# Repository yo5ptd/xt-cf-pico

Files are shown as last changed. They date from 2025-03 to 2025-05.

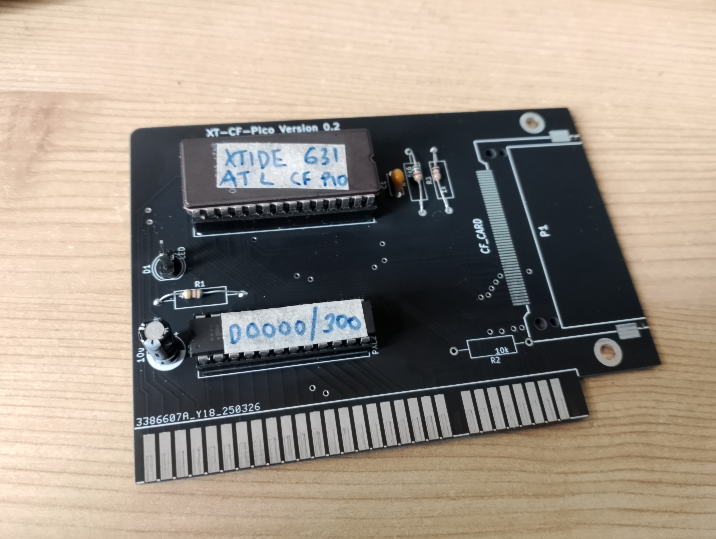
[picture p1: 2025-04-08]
images/during assembly.jpg

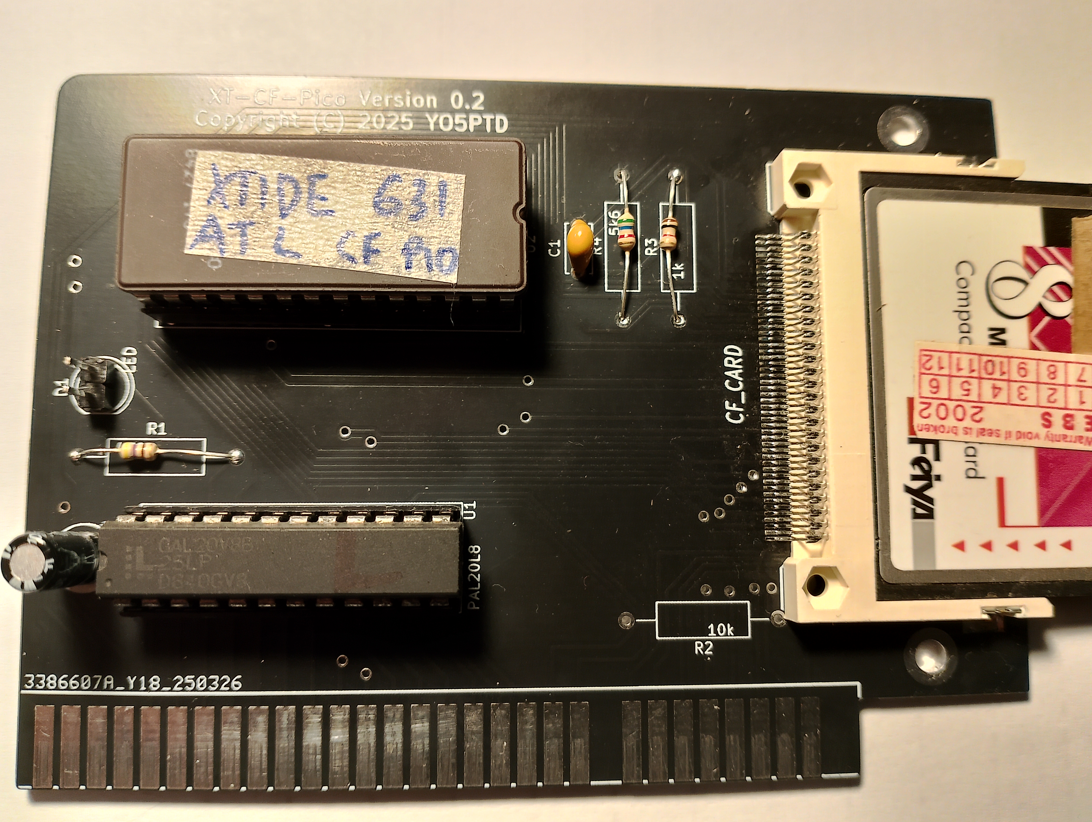
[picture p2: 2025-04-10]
images/assembled.jpg

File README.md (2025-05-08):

# xt-cf-pico   
8-bit ISA interface for Compact Flash cards with a single PLD  

## Introduction

XT-CF-Pico is a remake of Sergey Kiselev  [xt-cf-lite-v4]  efectively reverting glue logic IC back to PLD but still using through hole components. This card allows connecting a Compact Flash (CF) card to computers with ISA bus and using it as a mass storage device. The card also supports BIOS extension ROM, but if you have it e.g. in a network adapter already, it's safe to leave it out.

* 16 KiB EEPROM (28128) with either 8 or 16k images, no flash ROM.
* no jumpers, everything you configure in the PLD (GAL20V8, still available on Aliexpress, used in projects like C64 PLA20V8)

This is my first ISA board and first PLD design, it was easy to debug by just rewriting the GAL and EPROM! My motivation was that there were too many components and a lot of unused pins on Sergey's design.

## Hardware Documentation
The idea was to use a minimum amount of components that were available late '80s, keeping Sergey's concept of having them all through hole (except of course the CF adapter). Result was one GAL IC and one EPROM.

Download latest bios from https://www.xtideuniversalbios.org/binaries/ (I used IDE_ATL.BIN) and configure primary IDE (with xtidecfg.com) for XT CF BIU 8 (I used addr 0x300).
[XTCFG](images/biu.jpg) 

### Schematic and PCB Layout

[Schematic](KiCad/XT-CF-Pico-Schematic.pdf)

[PCB Layout](KiCad/XT-CF-Pico-Board.pdf)

[Assembled](images/assembled.jpg)

### Bill of Materials

Component Type | Reference | Description                             | Quantity | Possible Sources and Notes
-------------- | --------- | --------------------------------------- | -------- | --------------------------
PCB            |           | XT-CF-Pico 	                           | 1        | jlpcb
Capacitor      | C1        | 0.1 uF ceramic, 5.0 mm lead spacing     | 1        | 
Capacitor      | C2 	     | 10 uF electrolytic, 6.3 mm lead spacing | 1        | 
LED            | D1        | 5 m (T-1) LED indicator                 | 1        | You can use 2 pin jumper holder for external led
Connector      | P1        | Compact Flash Card connector            | 1        | 101D-TAAA-R01 from ATTEND  (this was the cheapest now, footprint was updated)
Resistor       | R1        | 470 Ohm, 1/4 W                          | 1        | Mouser 291-470-RC
Resistor       | R3        | 1 kOhm, 1/4 W                           | 1        | Mouser 291-1K-RC
Resistor       | R4        | 5.6 kOhm, 1/4 W                         | 1        | Mouser 291-5.6K-RC
Resistor       | R2        | 10 kOhm, 1/4 W                          | 0        | Note: Do not install, kept for historic reasons only (card present detection?)
IC             | U1        | 27128 EEPROM                            | 1        | mbm27128
IC Socket      | U1        | 28 pin 600 mil (wide) DIP socket        | 1        | optional
IC Socket      | U2        | 24 pin 300 mil (narrow) DIP socket      | 1        | optional

### Cost estimate for 5 boards

* PCB - 4.17 USD including shipping jlpcb
* GAL20V8 - 3.47 USD including shipping aliexpress
* 28C128 - 5.49 USD including shipping aliexpress
* 101D-TAAA-R01 attend - 10.4 including shipping from tme
* passives - 1USD or less (you can order them from tme to save on shipping)

Results a cost of around 5 USD per board (not including labor to assemble and program)

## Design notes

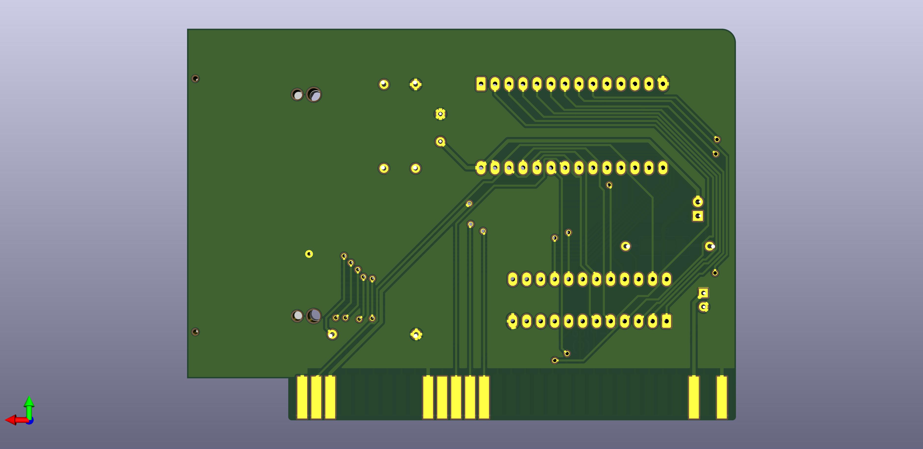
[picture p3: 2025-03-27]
images/xt-cf-back.jpg

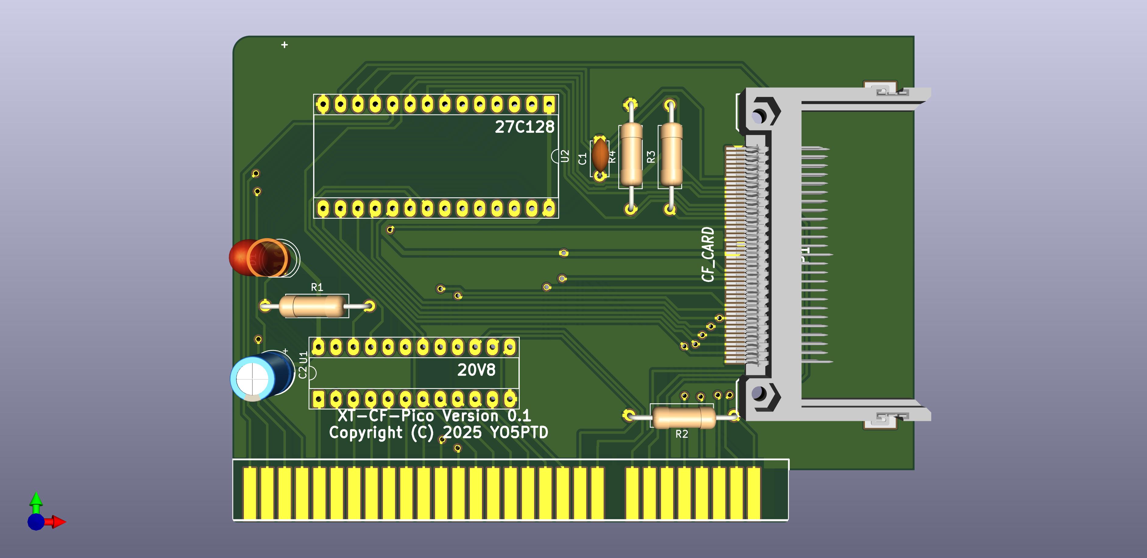
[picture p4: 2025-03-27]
images/xt-cf.jpg

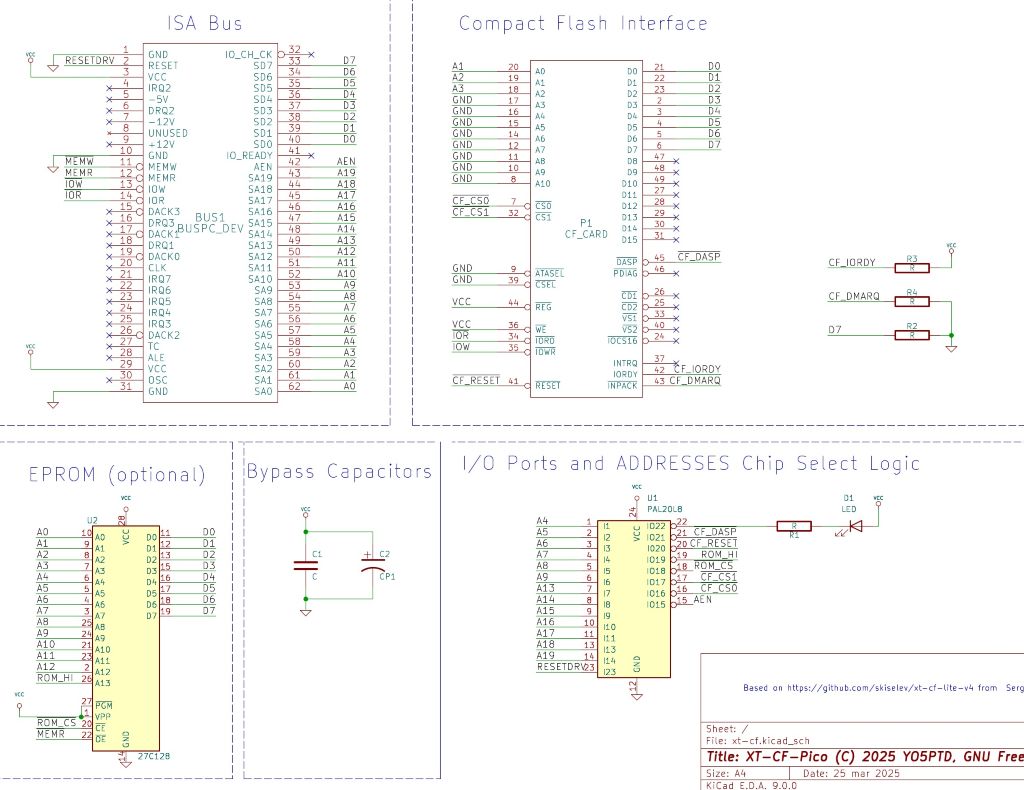
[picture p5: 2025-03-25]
images/sch.jpg

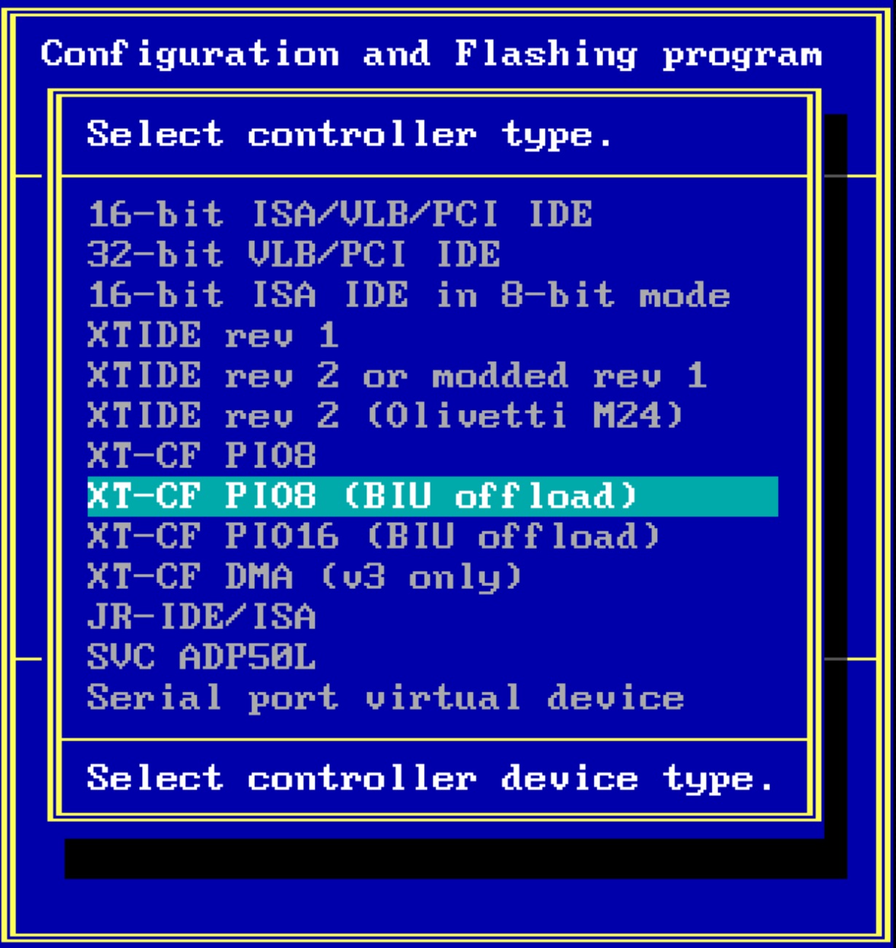
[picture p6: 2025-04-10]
images/biu.jpg

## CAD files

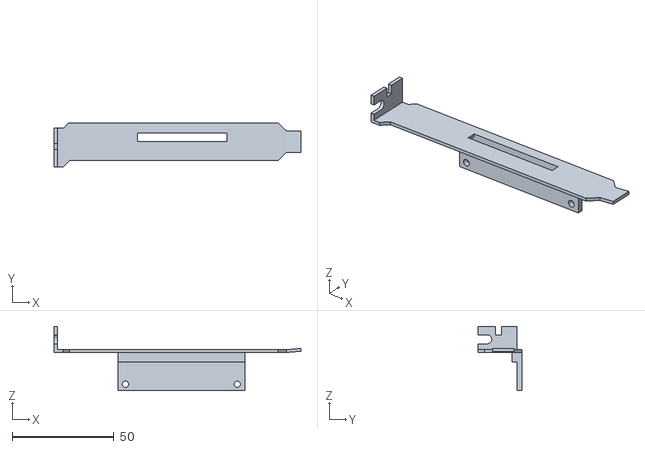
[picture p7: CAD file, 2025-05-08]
bracket/bracket.stl
121.4 x 21.6 x 31.5

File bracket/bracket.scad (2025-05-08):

resolution=32; // $fn
low_profile=0; // [0:false, 1:true]
bracket_thickness = 1.4; // base bracket depth

angled_bottom_tab = 1; // [0:false, 1:true]
decorative_hole=0; // [0:false, 1:true]
isa_slot=1; // [0:false, 1:true]
pcb_thickness=1.6;
top_tab_thickness = 1.6;
/* [Screw mount tabs] */

first_screw_tab_enabled = 1; // [0:false, 1:true]
second_screw_tab_enabled = 1; // [0:false, 1:true]
screw_mounts_on_bottom_of_pcb = 0; // [0:false, 1:true]
screw_mount_width = 7.5;
screw_mount_depth = 2.5;
screw_mount_hole_r = 1.55; // m3 bolt
screw_mount_thread_distance_base = 15.6;
screw_mount_inset_r = 2.9; // m3 bolt head
screw_mount_inset_depth = 0;
screw_mount_caulking = 0.5;

first_mount_x = 33.5;
mount_hole_distance = 55;
// If on top of the PCB, it is recommended to have this be at least the thickness of the PCB
screw_mount_y = 0;
second_mount_x = first_mount_x + mount_hole_distance;

/* [Round Holes] */
hole_1_enabled = 0; // [0:false, 1:true]
// X is offset from the first screw hole (i.e. the screw hole closest to the case mount cutout)
hole_1_x = 11.01;
// Y is offset from top of pcb
hole_1_y = 6.5;
hole_1_d = 9.5;

hole_2_enabled = 0; // [0:false, 1:true]
hole_2_x = 24.34;
hole_2_y = 6.5;
hole_2_d = 9.5;

hole_3_enabled = 0; // [0:false, 1:true]
hole_3_x = 63.41;
hole_3_y = 7;
hole_3_d = 6;

hole_4_enabled = 0; // [0:false, 1:true]
hole_4_x = 76.12;
hole_4_y = 7;
hole_4_d = 6;

hole_5_enabled = 0; // [0:false, 1:true]
hole_5_x = 37.69;
hole_5_y = 6.5;
hole_5_d = 9.5;

hole_6_enabled = 0; // [0:false, 1:true]
hole_6_x = 51.04;
hole_6_y = 6.5;
hole_6_d = 9.5;

/* [Rectangular Holes] */
// hole is at center of x,y positions
rectangular_hole_1_enabled = 1; // [0:false, 1:true]
// X is offset from the first screw hole (i.e. the screw hole closest to the case mount cutout)
rectangular_hole_1_x = 11.00;
// Y is offset from top of pcb
rectangular_hole_1_y = 6.5;
rectangular_hole_1_w = 5;
rectangular_hole_1_h = 10.5;

rectangular_hole_2_enabled = 1; // [0:false, 1:true]
rectangular_hole_2_x = 20;
rectangular_hole_2_y = 6.5;
rectangular_hole_2_w = 5;
rectangular_hole_2_h = 10.5;

rectangular_hole_3_enabled = 1; // [0:false, 1:true]
rectangular_hole_3_x = 29;
rectangular_hole_3_y = 6.5;
rectangular_hole_3_w = 5;
rectangular_hole_3_h = 10.5;

rectangular_hole_4_enabled = 1; // [0:false, 1:true]
rectangular_hole_4_x = 38;
rectangular_hole_4_y = 6.5;
rectangular_hole_4_w = 5;
rectangular_hole_4_h = 10.5;

rectangular_hole_5_enabled = 1; // [0:false, 1:true]
rectangular_hole_5_x = 45;
rectangular_hole_5_y = 6.5;
rectangular_hole_5_w = 5;
rectangular_hole_5_h = 10.5;

rectangular_hole_6_enabled = 0; // [0:false, 1:true]
rectangular_hole_6_x = 51.04;
rectangular_hole_6_y = 6.5;
rectangular_hole_6_w = 10.5;
rectangular_hole_6_h = 10.5;
// values taken from https://content.norcomp.net/rohspdfs/Connectors/PanelCutOuts/Panel_Cutout_D-Sub-Single.pdf

/* [D-Sub holes (Serial/VGA/Gameport)] */
// hole is at center of x,y positions
dsub_hole_1_type = 0; // [0:None, 15.46:DB-9(VGA/Serial), 23.79:DB-15(Gameport), 37.51:DB-25(Parallel)]
// X is offset from the first screw hole (i.e. the screw hole closest to the case mount cutout)
dsub_hole_1_x = 37.6;
// Y is offset from top of pcb
dsub_hole_1_y = 7.1;
dsub_hole_1_invert = 0; // [0:false, 1:true]

dsub_hole_2_type = 0; // [0:None, 15.46:DB-9(VGA/Serial), 23.79:DB-15(Gameport), 37.51:DB-25(Parallel)]
dsub_hole_2_x = 37.6;
dsub_hole_2_y = 7.1;
dsub_hole_2_invert = 0; // [0:false, 1:true]

dsub_hole_3_type = 0; // [0:None, 15.46:DB-9(VGA/Serial), 23.79:DB-15(Gameport), 37.51:DB-25(Parallel)]
dsub_hole_3_x = 37.6;
dsub_hole_3_y = 7.1;
dsub_hole_3_invert = 0; // [0:false, 1:true]

/* [DVI Hole]] */

dvi_hole_enabled = 0; // [0:false, 1:true]
dvi_hole_x = 37.6;
dvi_hole_y = 6;
dvi_hole_invert = 0; // [0:false, 1:true]


module __Customizer_Limit__ () {}  // This actually works
shown_by_customizer = 0; // [0:false, 1:true]

$fn = resolution;
bracket_width_length = low_profile? 71.46 : 112.78;
bracket_length = low_profile ? 79.20 : 120.02;
bracket_width = 18.42 + 0;
bottom_tab_width = 10.19 + 0;
bracket_bottom_tab_angle_length = (bracket_width - bottom_tab_width) / 2;

bracket_reinforce_width = bracket_width * .2;
bracket_reinforce_length = bracket_length * .78;

bracket_hole_dia = decorative_hole ? 4.75 : 0;
bracket_hole_distance = low_profile ? 66.19 : 107.01;

screw_mount_thread_distance = screw_mount_thread_distance_base + bracket_thickness;
screw_mount_length = screw_mount_thread_distance * 1.1 + bracket_thickness;

bracket_reinforce_depth = 0;
bracket_reinforce_offset_x = -6;
bracket_reinforce_offset_y = -5;


module prism(l, w, h){
     polyhedron(
         points=[[0,0,0], [l,0,0], [l,w,0], [0,w,0], [0,w,h], [l,w,h]],
         faces=[[0,1,2,3],[5,4,3,2],[0,4,5,1],[0,3,4],[5,2,1]]
         );
}

// top notch
notch_width = 2.54;
notch_length = 3.94-.86; // 3.94 - specified thickness of .86mm (vs actual thickness)

top_tab_width = 19.05; // had to fudge this
top_tab_length = 11.43;
top_tab_x = 0;
top_tab_y = 3.17; // 21.59 - 18.42
top_tab_screw_groove_dia = 4.42;
top_tab_screw_groove_fudge = -0.4; // kinda came out looking wrong so I'm faking it a bit here
top_tab_screw_groove_center = 3.18 + top_tab_screw_groove_fudge;
top_tab_screw_groove_distance = 6.35;
top_tab_screw_groove_translate_z = top_tab_length - top_tab_screw_groove_dia / 2 - top_tab_screw_groove_distance;

top_tab_useless_notch_length = 3.05;
top_tab_useless_notch_width = top_tab_screw_groove_distance - top_tab_screw_groove_dia / 2;
top_tab_useless_notch_z = top_tab_length - top_tab_useless_notch_width;
top_tab_useless_notch_y = top_tab_useless_notch_width / 2 + 8.05 - top_tab_useless_notch_length / 2;

translate([-top_tab_thickness + top_tab_x, -top_tab_y, 0]) difference() {
  cube([top_tab_thickness, top_tab_width, top_tab_length + bracket_thickness]);
  translate([-.5, -1, top_tab_screw_groove_translate_z + bracket_thickness]) {
    cube([top_tab_thickness + 1, top_tab_screw_groove_center * 2, top_tab_screw_groove_dia]);
    translate([1, top_tab_screw_groove_center * 2, top_tab_screw_groove_dia / 2])
      rotate([0, 90, 0])
      cylinder(r=top_tab_screw_groove_dia / 2, h=top_tab_thickness * 2, $fn=20, center=true);
  }
  translate([-.5, top_tab_useless_notch_y, top_tab_useless_notch_z + bracket_thickness]) {
    cube([top_tab_thickness + 1, top_tab_useless_notch_length, top_tab_useless_notch_width + 1]);
  }
}

// screw mounts
module screwmount(x) {
  
  translate([0, isa_slot? -screw_mount_y - screw_mount_depth : -bracket_width + screw_mount_y, 0]) // easier to be explicit here than factor it in the below statement
  translate([x - screw_mount_width / 2, bracket_width, -screw_mount_length + bracket_thickness])
    // cut out the threads
    difference() {
      union() {
        cube([screw_mount_width, screw_mount_depth, screw_mount_length]);
        //top caulking
        if ((isa_slot && bracket_width-screw_mount_y +screw_mount_caulking < bracket_width) || (!isa_slot &&  screw_mount_y + screw_mount_depth+ screw_mount_caulking < bracket_width)){
        difference(){
        translate([screw_mount_width, screw_mount_depth-.05, screw_mount_length-bracket_thickness-screw_mount_caulking +.05])
          rotate([90,0,180])
          prism(screw_mount_width,screw_mount_caulking+.05,screw_mount_caulking+.05);
        }
        }
        //bottom caulking
        if ((isa_slot && bracket_width-screw_mount_y -screw_mount_depth -screw_mount_caulking > 0) || (!isa_slot && screw_mount_y - screw_mount_caulking > 0)){
        translate([0, 0, screw_mount_length-bracket_thickness-screw_mount_caulking +.05])
          rotate([90,0,0])
          prism(screw_mount_width,screw_mount_caulking+.05,screw_mount_caulking+.05);
        }        
      }
       translate([screw_mount_width / 2, -2, screw_mount_length - screw_mount_thread_distance])
         rotate([0, 90, 90]) cylinder(r=screw_mount_hole_r, h=10, $fn=20);
      //inset
      translate([screw_mount_width / 2, ((isa_slot && screw_mounts_on_bottom_of_pcb) || (!isa_slot && !screw_mounts_on_bottom_of_pcb))?(screw_mount_depth - screw_mount_inset_depth + 0.01):(-0.01),
        screw_mount_length - screw_mount_thread_distance])
          rotate([0, 90, 90])
          cylinder(r=screw_mount_inset_r, h=screw_mount_inset_depth, $fn=20);
    }
    
///hack
translate([first_mount_x+ screw_mount_width / 2, bracket_width-screw_mount_depth, -screw_mount_length + bracket_thickness])
     cube([second_mount_x-first_mount_x-screw_mount_width , screw_mount_depth, screw_mount_length]);
    
translate([first_mount_x- screw_mount_width / 2, bracket_width-2*screw_mount_depth, -6 + bracket_thickness])
     cube([second_mount_x-first_mount_x+screw_mount_width , screw_mount_depth, 6]);
}

if (first_screw_tab_enabled){
  screwmount(first_mount_x);  
}
if (second_screw_tab_enabled) {
  screwmount(second_mount_x);
}

// bottom notch
shiftover_width = top_tab_y;
shiftover_length = 2.92;
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

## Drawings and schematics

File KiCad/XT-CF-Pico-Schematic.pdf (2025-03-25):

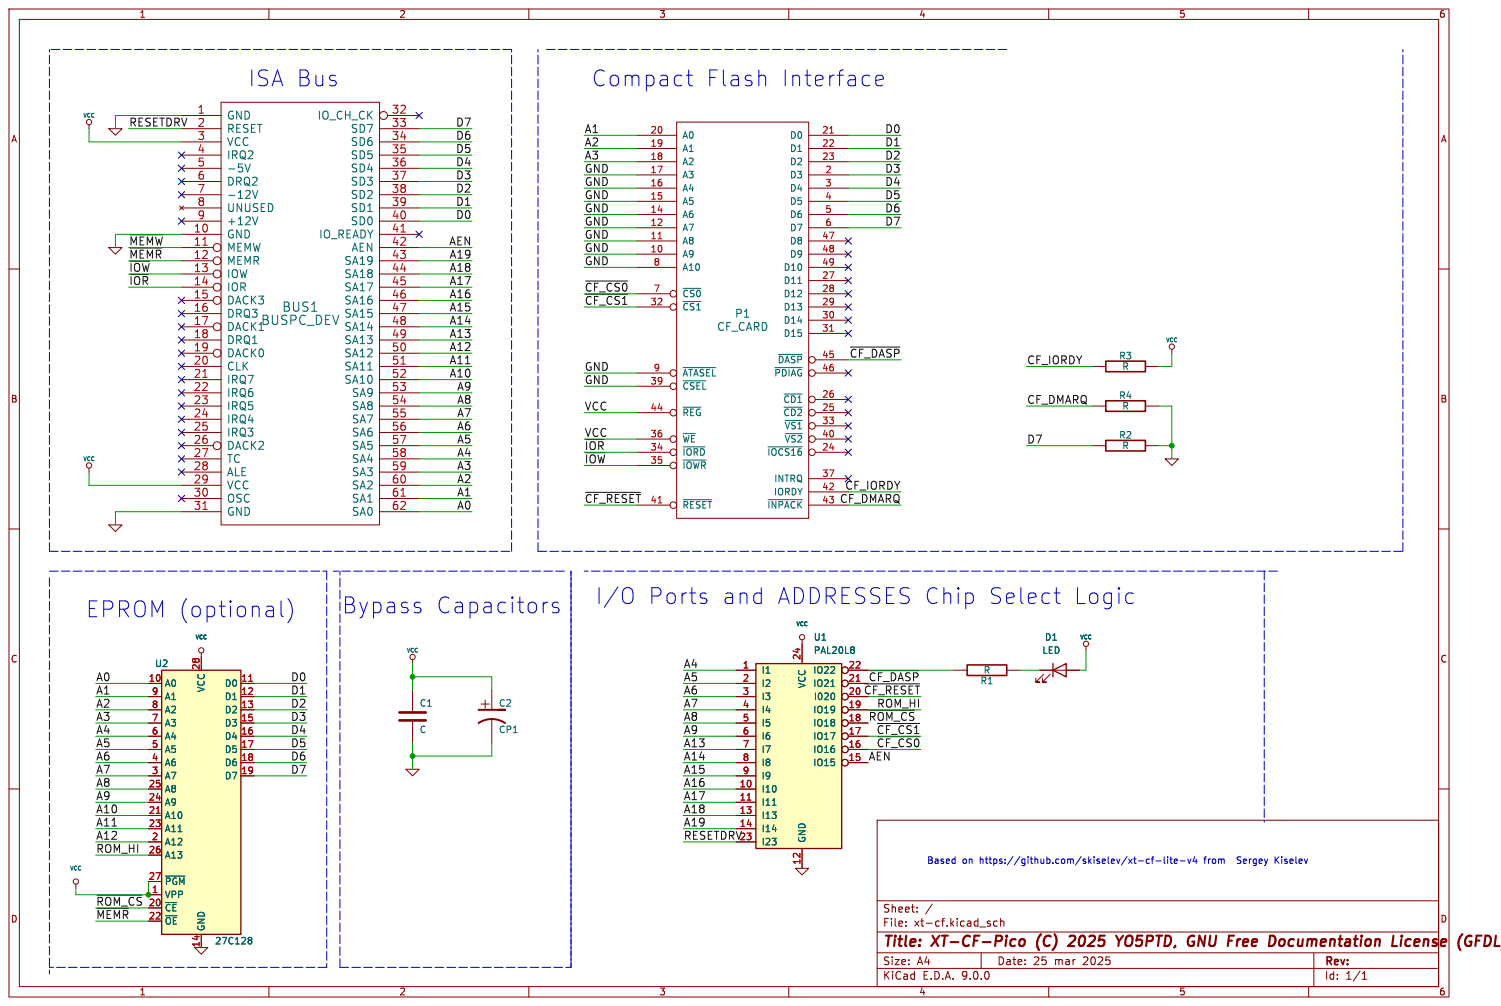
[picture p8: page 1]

I/O Ports and ADDRESSES Chip Select Logic

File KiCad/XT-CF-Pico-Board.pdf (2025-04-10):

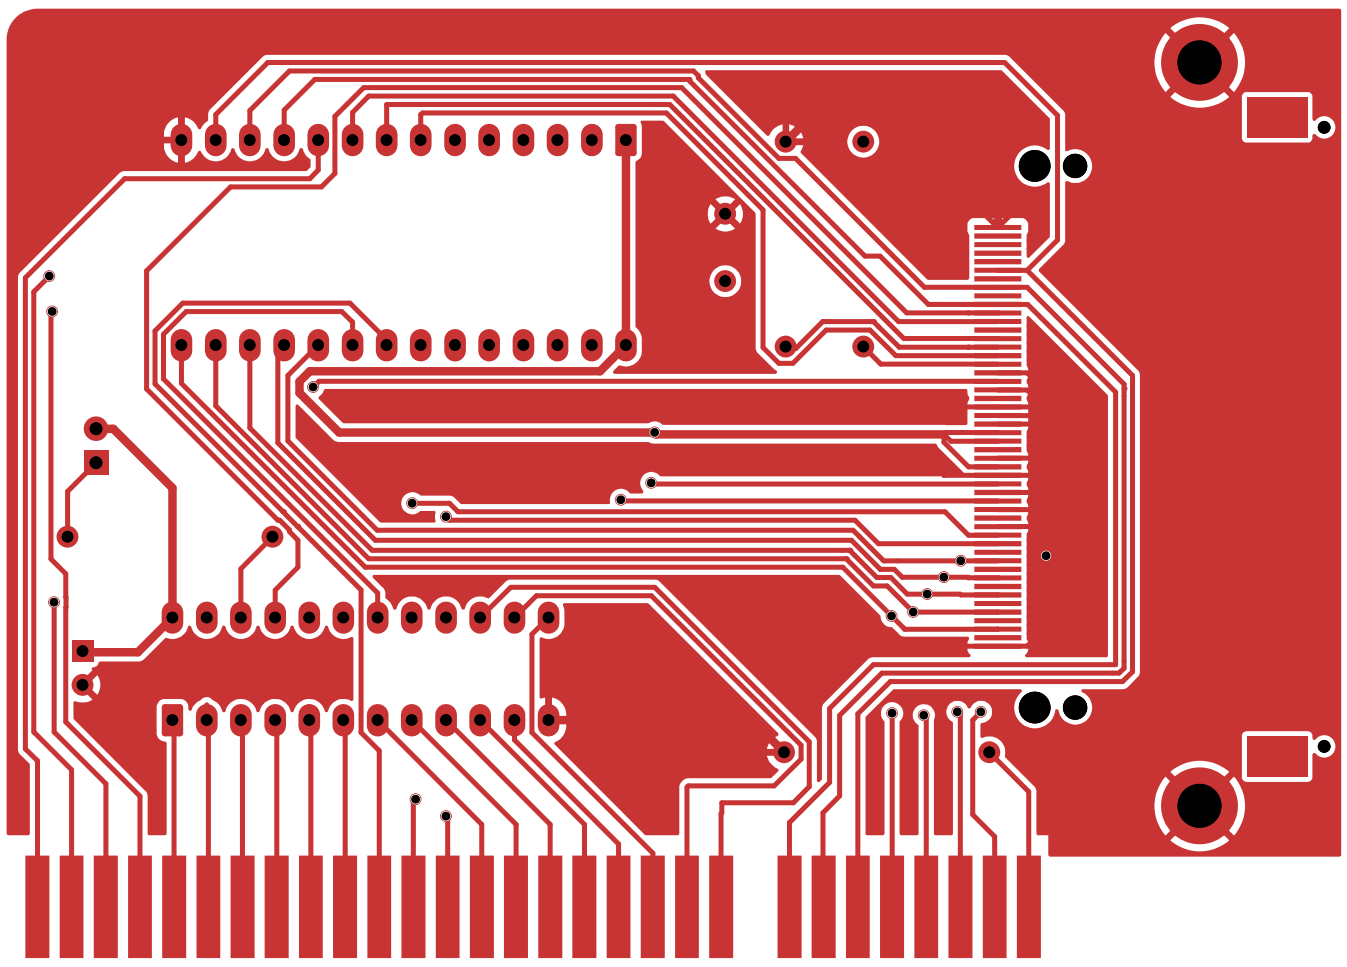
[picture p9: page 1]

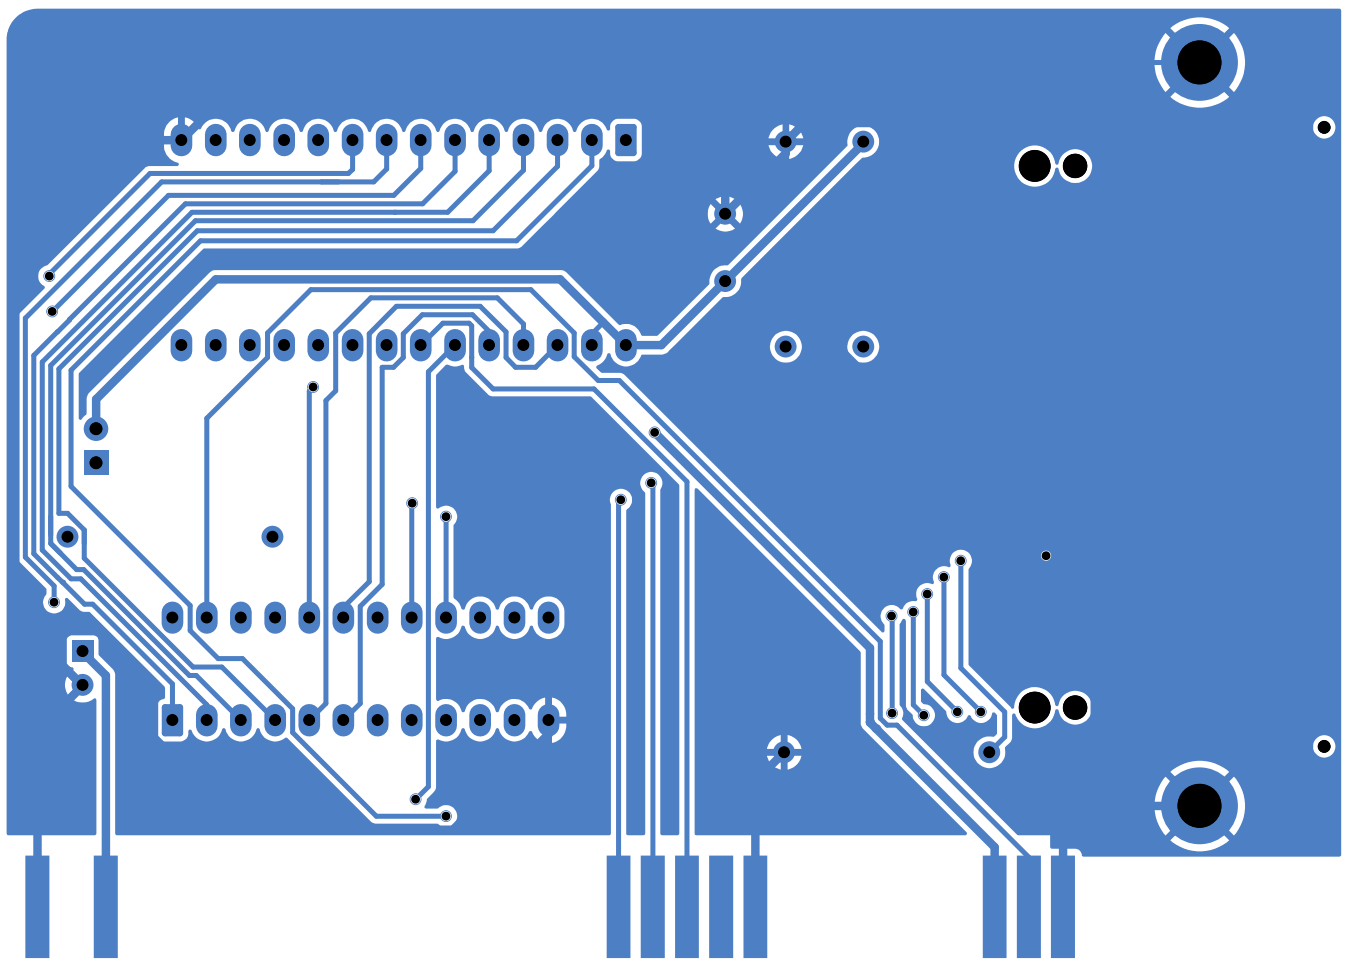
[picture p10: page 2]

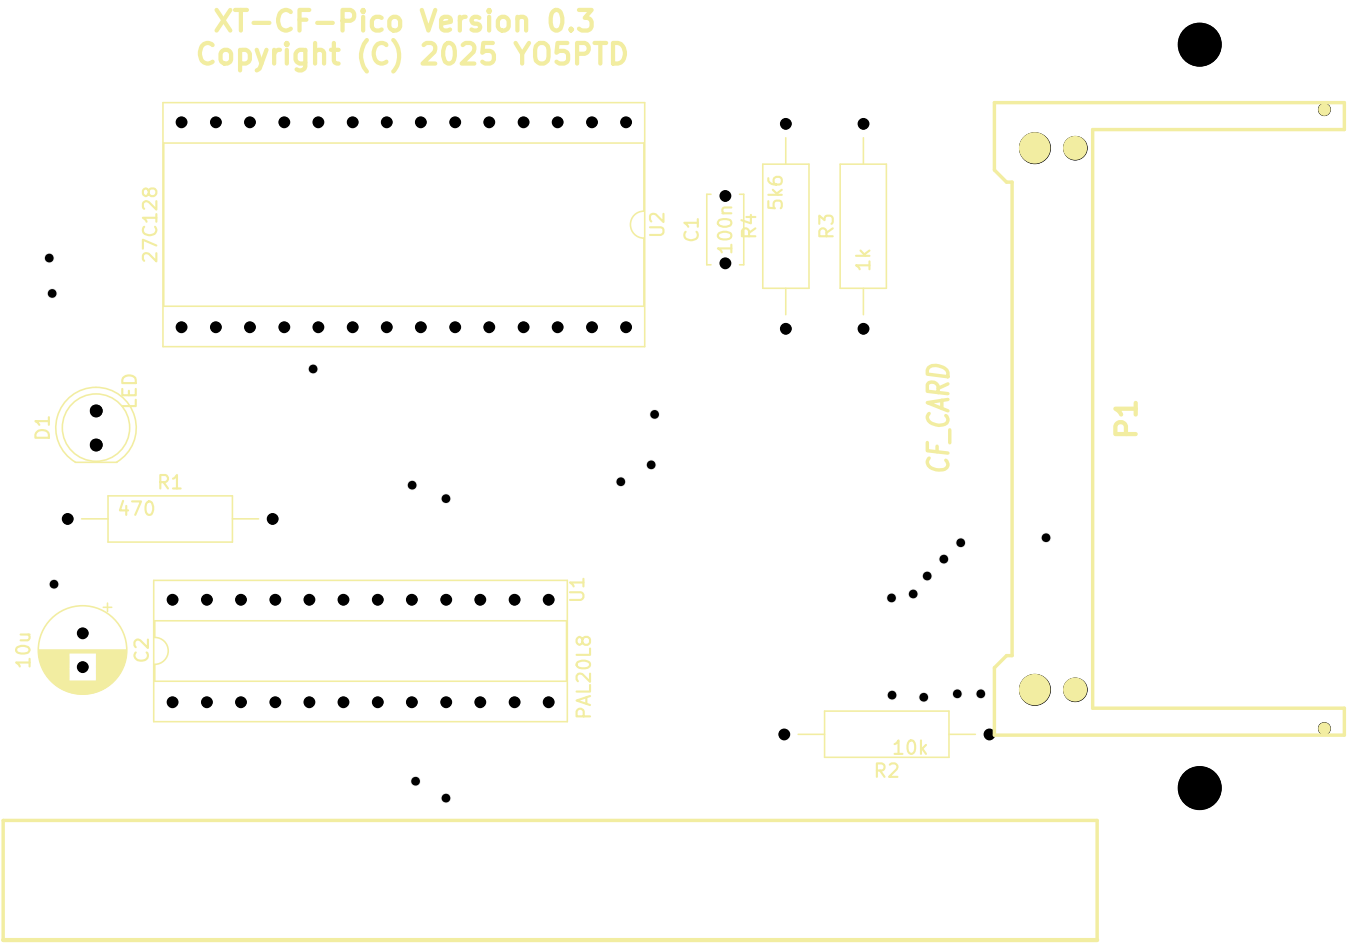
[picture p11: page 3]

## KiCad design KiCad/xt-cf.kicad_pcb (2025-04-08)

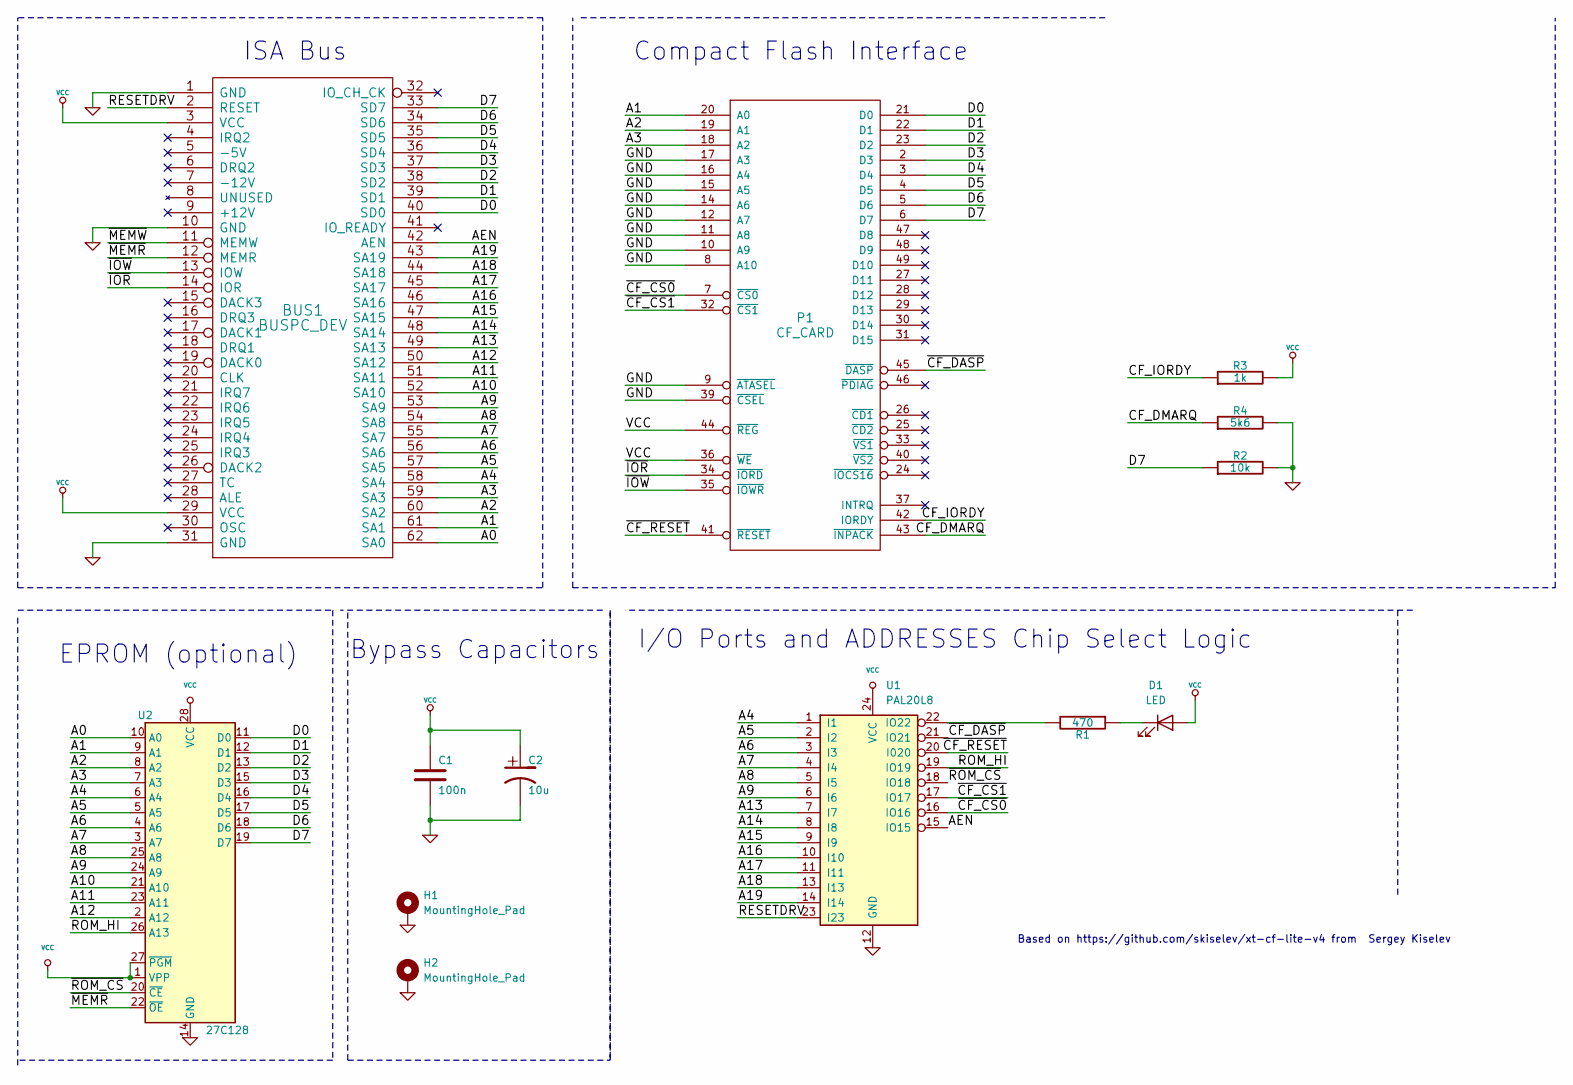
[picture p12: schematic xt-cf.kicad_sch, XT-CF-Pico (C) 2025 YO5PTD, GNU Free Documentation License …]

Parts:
BUS1: BUSPC_DEV; Conn_Bus_ISA8
C1: 100n; C_Disc_D5.0mm_W2.5mm_P5.00mm
C2: 10u; CP_Radial_D6.3mm_P2.50mm
D1: LED; LED_D5.0mm
H1, H2: MountingHole_Pad; MountingHole_3.2mm_M3_ISO7380_Pad
P1: CF_CARD; CF_N7E50-Q516XX-40
R1: 470; R_Axial_DIN0309_L9.0mm_D3.2mm_P15.24mm_Horizontal
R2: 10k; R_Axial_DIN0309_L9.0mm_D3.2mm_P15.24mm_Horizontal
R3: 1k; R_Axial_DIN0309_L9.0mm_D3.2mm_P15.24mm_Horizontal
R4: 5k6; R_Axial_DIN0309_L9.0mm_D3.2mm_P15.24mm_Horizontal
U1: PAL20L8; CERDIP-24_W7.62mm_SideBrazed_LongPads_Socket
U2: 27C128; DIP-28_W15.24mm_Socket_LongPads

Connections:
/A0: BUS1.62 (SA0), U2.10 (A0)
/A1: BUS1.61 (SA1), P1.20 (A0), U2.9 (A1)
/A2: BUS1.60 (SA2), P1.19 (A1), U2.8 (A2)
/A3: BUS1.59 (SA3), P1.18 (A2), U2.7 (A3)
/A4: BUS1.58 (SA4), U1.1 (I1), U2.6 (A4)
/A5: BUS1.57 (SA5), U1.2 (I2), U2.5 (A5)
/A6: BUS1.56 (SA6), U1.3 (I3), U2.4 (A6)
/A7: BUS1.55 (SA7), U1.4 (I4), U2.3 (A7)
/A8: BUS1.54 (SA8), U1.5 (I5), U2.25 (A8)
/A9: BUS1.53 (SA9), U1.6 (I6), U2.24 (A9)
/A10: BUS1.52 (SA10), U2.21 (A10)
/A11: BUS1.51 (SA11), U2.23 (A11)
/A12: BUS1.50 (SA12), U2.2 (A12)
/A13: BUS1.49 (SA13), U1.7 (I7)
/A14: BUS1.48 (SA14), U1.8 (I8)
/A15: BUS1.47 (SA15), U1.9 (I9)
/A16: BUS1.46 (SA16), U1.10 (I10)
/A17: BUS1.45 (SA17), U1.11 (I11)
/A18: BUS1.44 (SA18), U1.13 (I13)
/A19: BUS1.43 (SA19), U1.14 (I14)
/AEN: BUS1.42 (AEN), U1.15 (IO15)
/CF_DMARQ: P1.43 (~INPACK), R4.1
/CF_IORDY: P1.42 (IORDY), R3.1
/D0: BUS1.40 (SD0), P1.21 (D0), U2.11 (D0)
/D1: BUS1.39 (SD1), P1.22 (D1), U2.12 (D1)
/D2: BUS1.38 (SD2), P1.23 (D2), U2.13 (D2)
/D3: BUS1.37 (SD3), P1.2 (D3), U2.15 (D3)
/D4: BUS1.36 (SD4), P1.3 (D4), U2.16 (D4)
/D5: BUS1.35 (SD5), P1.4 (D5), U2.17 (D5)
/D6: BUS1.34 (SD6), P1.5 (D6), U2.18 (D6)
/D7: BUS1.33 (SD7), P1.6 (D7), R2.1, U2.19 (D7)
/RESETDRV: BUS1.2 (RESET), U1.23 (I23)
/ROM_HI: U1.19 (IO19), U2.26 (A13)
/~CF_CS0: P1.7 (~CS0), U1.16 (IO16)
/~CF_CS1: P1.32 (~CS1), U1.17 (IO17)
/~CF_DASP: P1.45 (~DASP), U1.21 (IO21)
/~CF_RESET: P1.41 (~RESET), U1.20 (I020)
/~IOR: BUS1.14 (IOR), P1.34 (~IORD)
/~IOW: BUS1.13 (IOW), P1.35 (~IOWR)
/~MEMR: BUS1.12 (MEMR), U2.22 (~OE)
/~MEMW: BUS1.11 (MEMW)
/~ROM_CS: U1.18 (IO18), U2.20 (~CE)
GND: BUS1.1 (GND), BUS1.10 (GND), BUS1.31 (GND), C1.2, C2.2, H1.1, H2.1, P1.1 (GND), P1.8 (A10), P1.9 (~ATASEL), P1.10 (A9), P1.11 (A8), P1.12 (A7), P1.14 (A6), P1.15 (A5), P1.16 (A4), P1.17 (A3), P1.39 (~CSEL), P1.50 (GND), R2.2, R4.2, U1.12 (GND), U2.14 (GND)
unnamed: D1.1 (K), R1.1
unnamed: R1.2, U1.22 (IO22)
VCC: BUS1.3 (VCC), BUS1.29 (VCC), C1.1, C2.1, D1.2 (A), P1.13 (VCC), P1.36 (~WE), P1.38 (VCC), P1.44 (~REG), R3.2, U1.24 (VCC), U2.1 (VPP), U2.27 (~PGM), U2.28 (VCC)

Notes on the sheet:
ISA Bus
Bypass Capacitors
Based on https://github.com/skiselev/xt-cf-lite-v4 from Sergey Kiselev
I/O Ports and ADDRESSES Chip Select Logic
EPROM (optional)
Compact Flash Interface

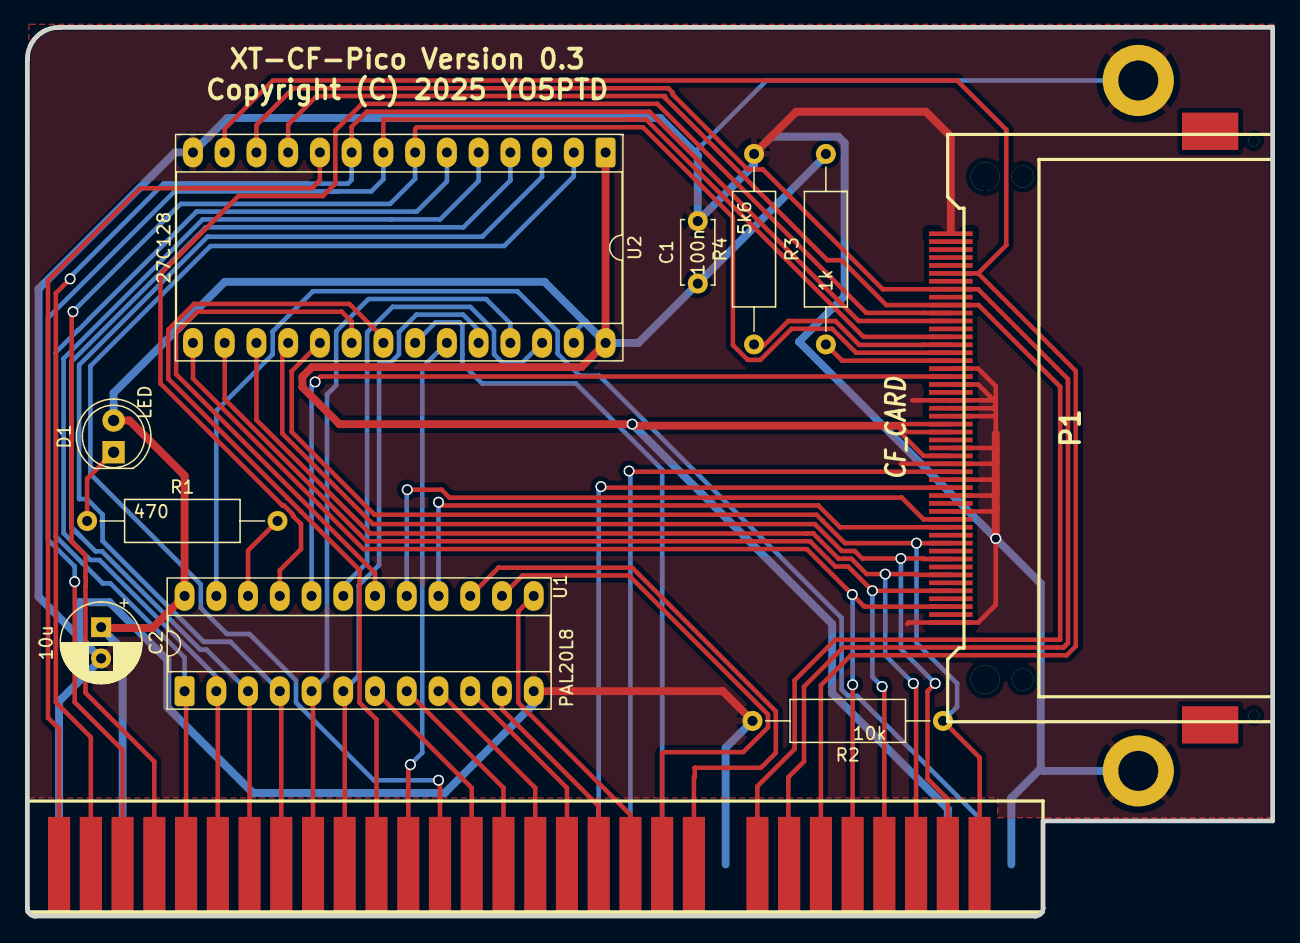
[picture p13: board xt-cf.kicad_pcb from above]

Board: 2 copper layers, 99.7 x 71.1 mm, 13 parts (0 on the bottom side), 45 nets.

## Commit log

2025-03-27 Some touchups, gerbers that were sent to JLPCB ver 0.2
    [xt-cf-B_Mask.gbs, xt-cf-B_Paste.gbp, xt-cf-B_Silkscreen.gbo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]
2025-04-08 Added 3d printed bracket
    [bracket.scad, bracket.stl]
2025-05-08 Fix for PLD A4 - read reliability issues
    [bracket.scad, bracket.stl]

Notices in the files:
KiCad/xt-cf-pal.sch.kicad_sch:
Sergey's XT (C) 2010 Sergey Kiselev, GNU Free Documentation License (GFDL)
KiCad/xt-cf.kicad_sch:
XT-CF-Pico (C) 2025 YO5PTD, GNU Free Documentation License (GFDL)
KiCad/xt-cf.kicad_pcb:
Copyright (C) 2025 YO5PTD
